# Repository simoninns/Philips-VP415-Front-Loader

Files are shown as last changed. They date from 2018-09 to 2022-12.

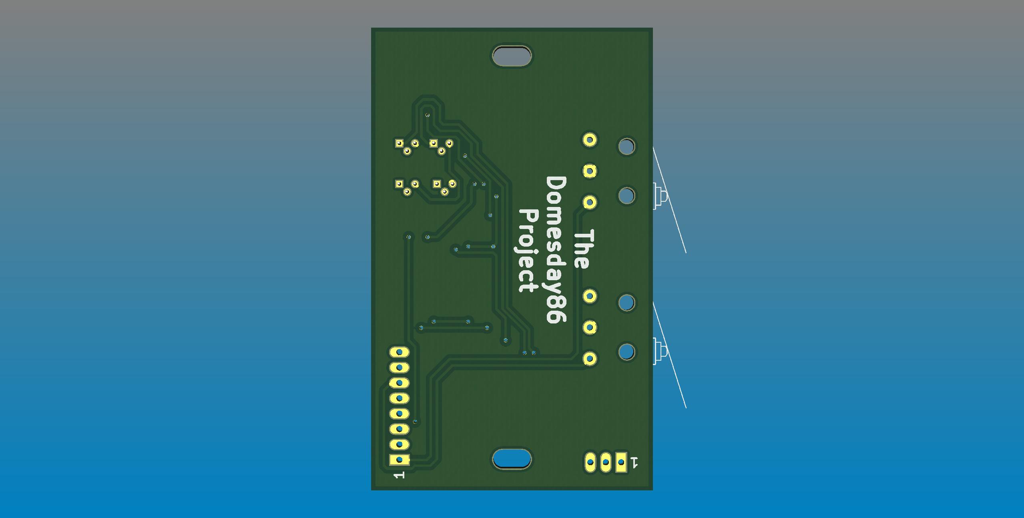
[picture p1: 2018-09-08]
Philips-VP415-Front-Loader PCB bottom.jpg

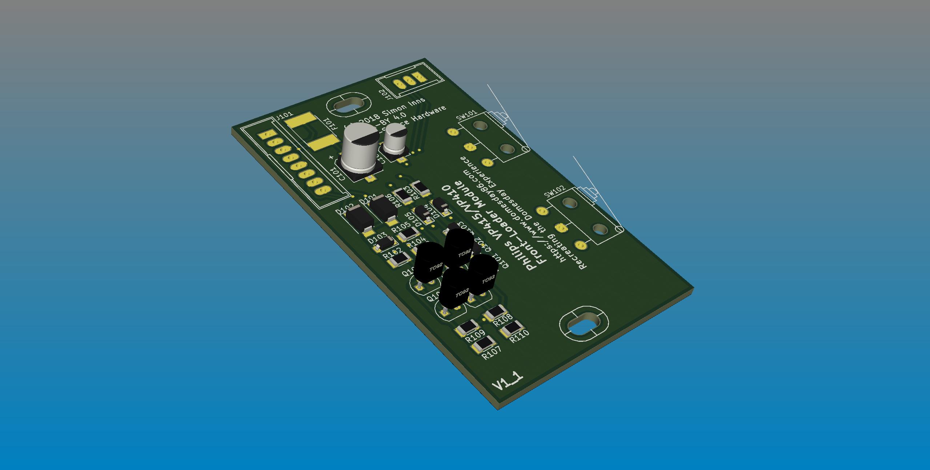
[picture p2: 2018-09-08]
Philips-VP415-Front-Loader PCB 3D render.jpg

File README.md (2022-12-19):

# Philips-VP415-Front-Loader
Replacement front-loader module (P) for the Philips VP415 Domesday LaserVision player

For more information, please see [the project wiki](https://github.com/simoninns/Philips-VP415-Front-Loader/wiki)

## Synopsis

This card is designed as a drop-in replacement for the original Philips VP415 LaserVision player's front-loader module (P).

## Motivation

The original front loader module uses custom Philips microswitches which can no longer be sourced.  The front-loader module is responsible for detecting the closure of the disc tray and the switches are impacted everytime a LaserDisc is loaded making it a common failure point in VP415s.  In addition, since the disc tray can vibrate during transport, the front-loader module is often damaged when players are moved.

The new module design is intended to use modern components and act as a drop-in replacement for the original requiring no alteration to the VP415.

## Author

The Philips VP415 replacement front-loader module was designed by Simon Inns.

## License

This project is released under a Creative Commons Attribution-ShareAlike 4.0 International (CC BY-SA 4.0) licence.

You are free to:

Share � copy and redistribute the material in any medium or format
Adapt � remix, transform, and build upon the material
for any purpose, even commercially.

This license is acceptable for Free Cultural Works.

The licensor cannot revoke these freedoms as long as you follow the license terms.

Under the following terms:

Attribution � You must give appropriate credit, provide a link to the license,
and indicate if changes were made. You may do so in any reasonable manner, but
not in any way that suggests the licensor endorses you or your use.

ShareAlike � If you remix, transform, or build upon the material, you must
distribute your contributions under the same license as the original.

No additional restrictions � You may not apply legal terms or technological
measures that legally restrict others from doing anything the license permits.

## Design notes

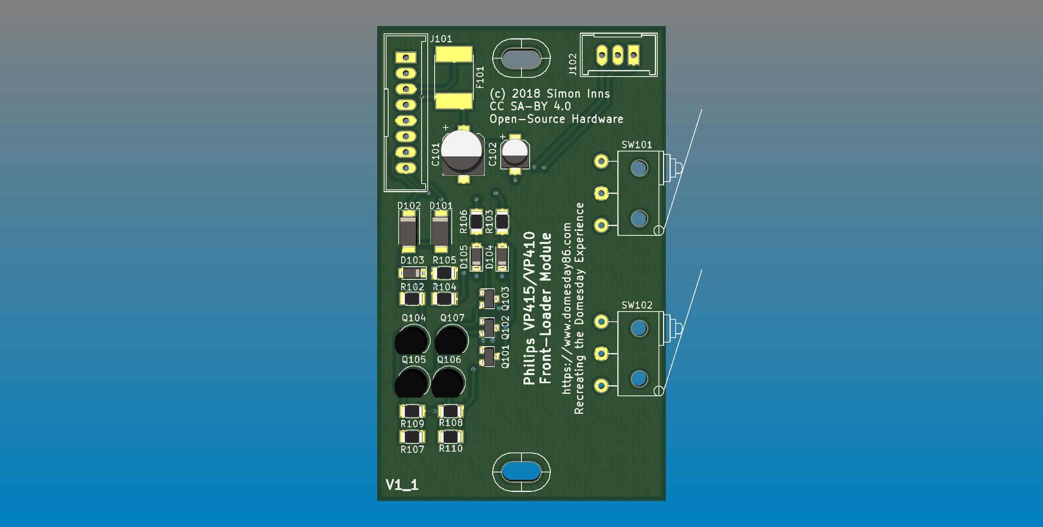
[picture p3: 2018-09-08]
Philips-VP415-Front-Loader PCB top.jpg

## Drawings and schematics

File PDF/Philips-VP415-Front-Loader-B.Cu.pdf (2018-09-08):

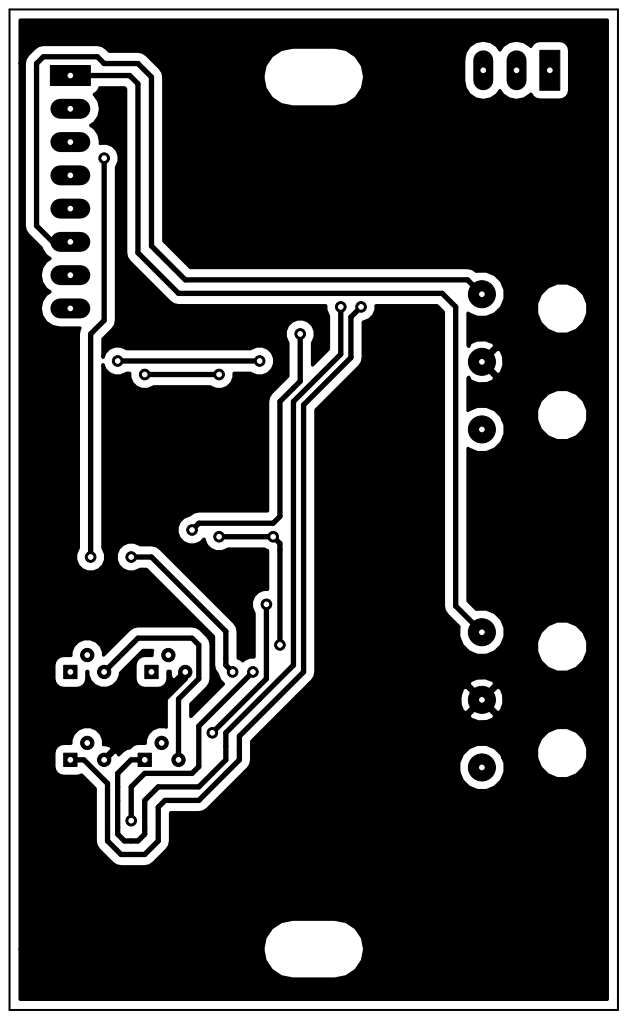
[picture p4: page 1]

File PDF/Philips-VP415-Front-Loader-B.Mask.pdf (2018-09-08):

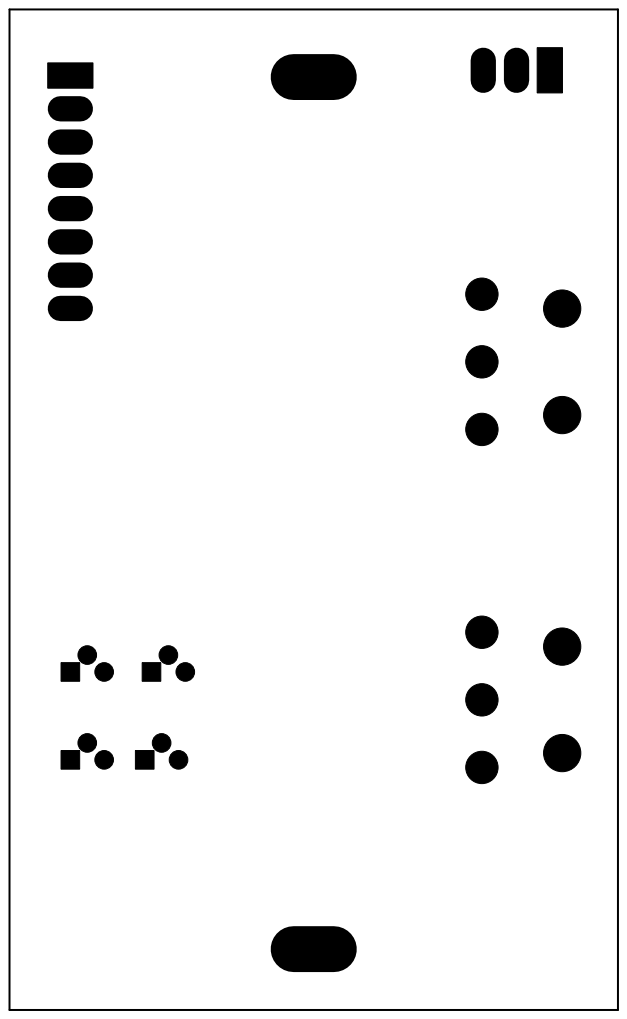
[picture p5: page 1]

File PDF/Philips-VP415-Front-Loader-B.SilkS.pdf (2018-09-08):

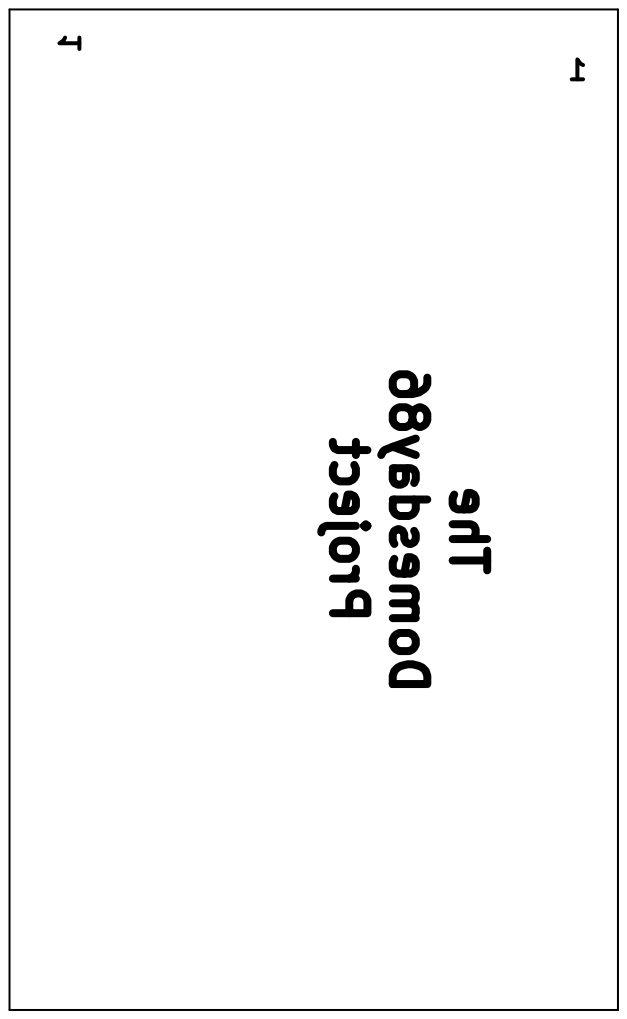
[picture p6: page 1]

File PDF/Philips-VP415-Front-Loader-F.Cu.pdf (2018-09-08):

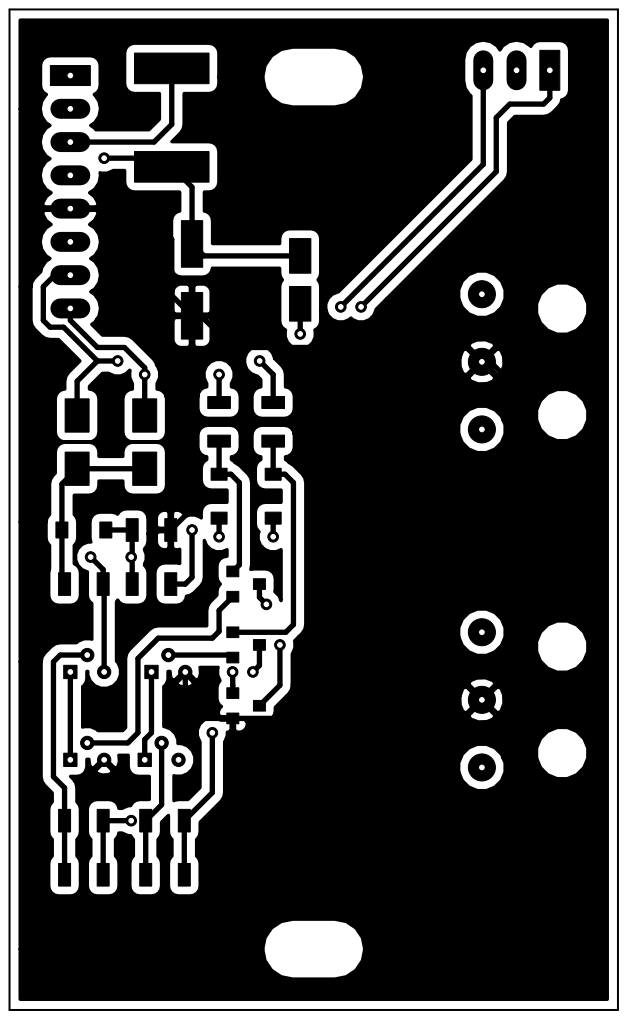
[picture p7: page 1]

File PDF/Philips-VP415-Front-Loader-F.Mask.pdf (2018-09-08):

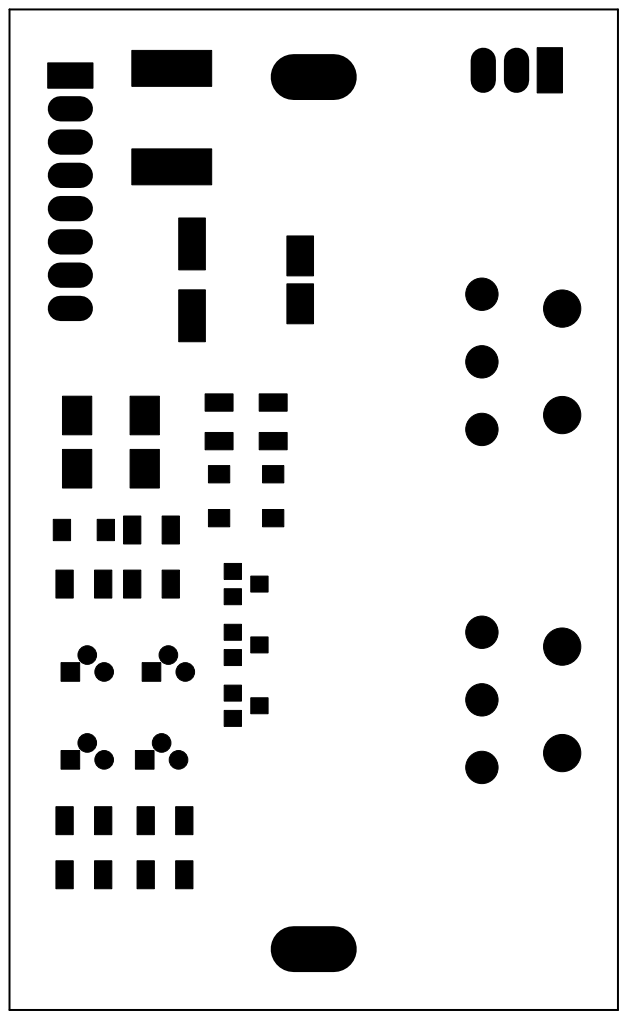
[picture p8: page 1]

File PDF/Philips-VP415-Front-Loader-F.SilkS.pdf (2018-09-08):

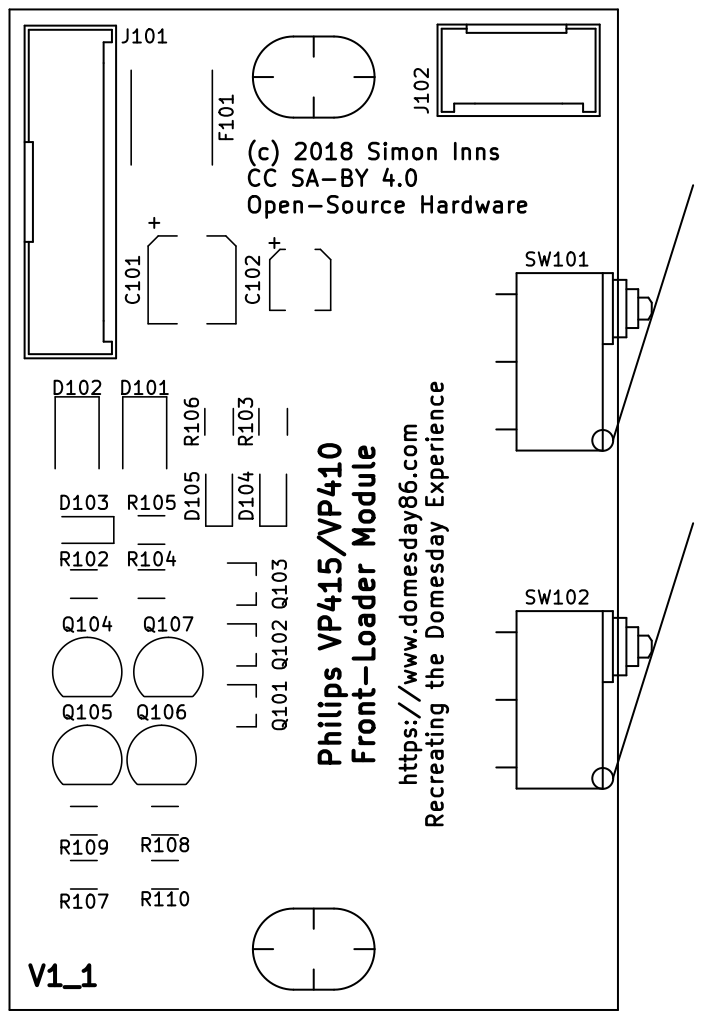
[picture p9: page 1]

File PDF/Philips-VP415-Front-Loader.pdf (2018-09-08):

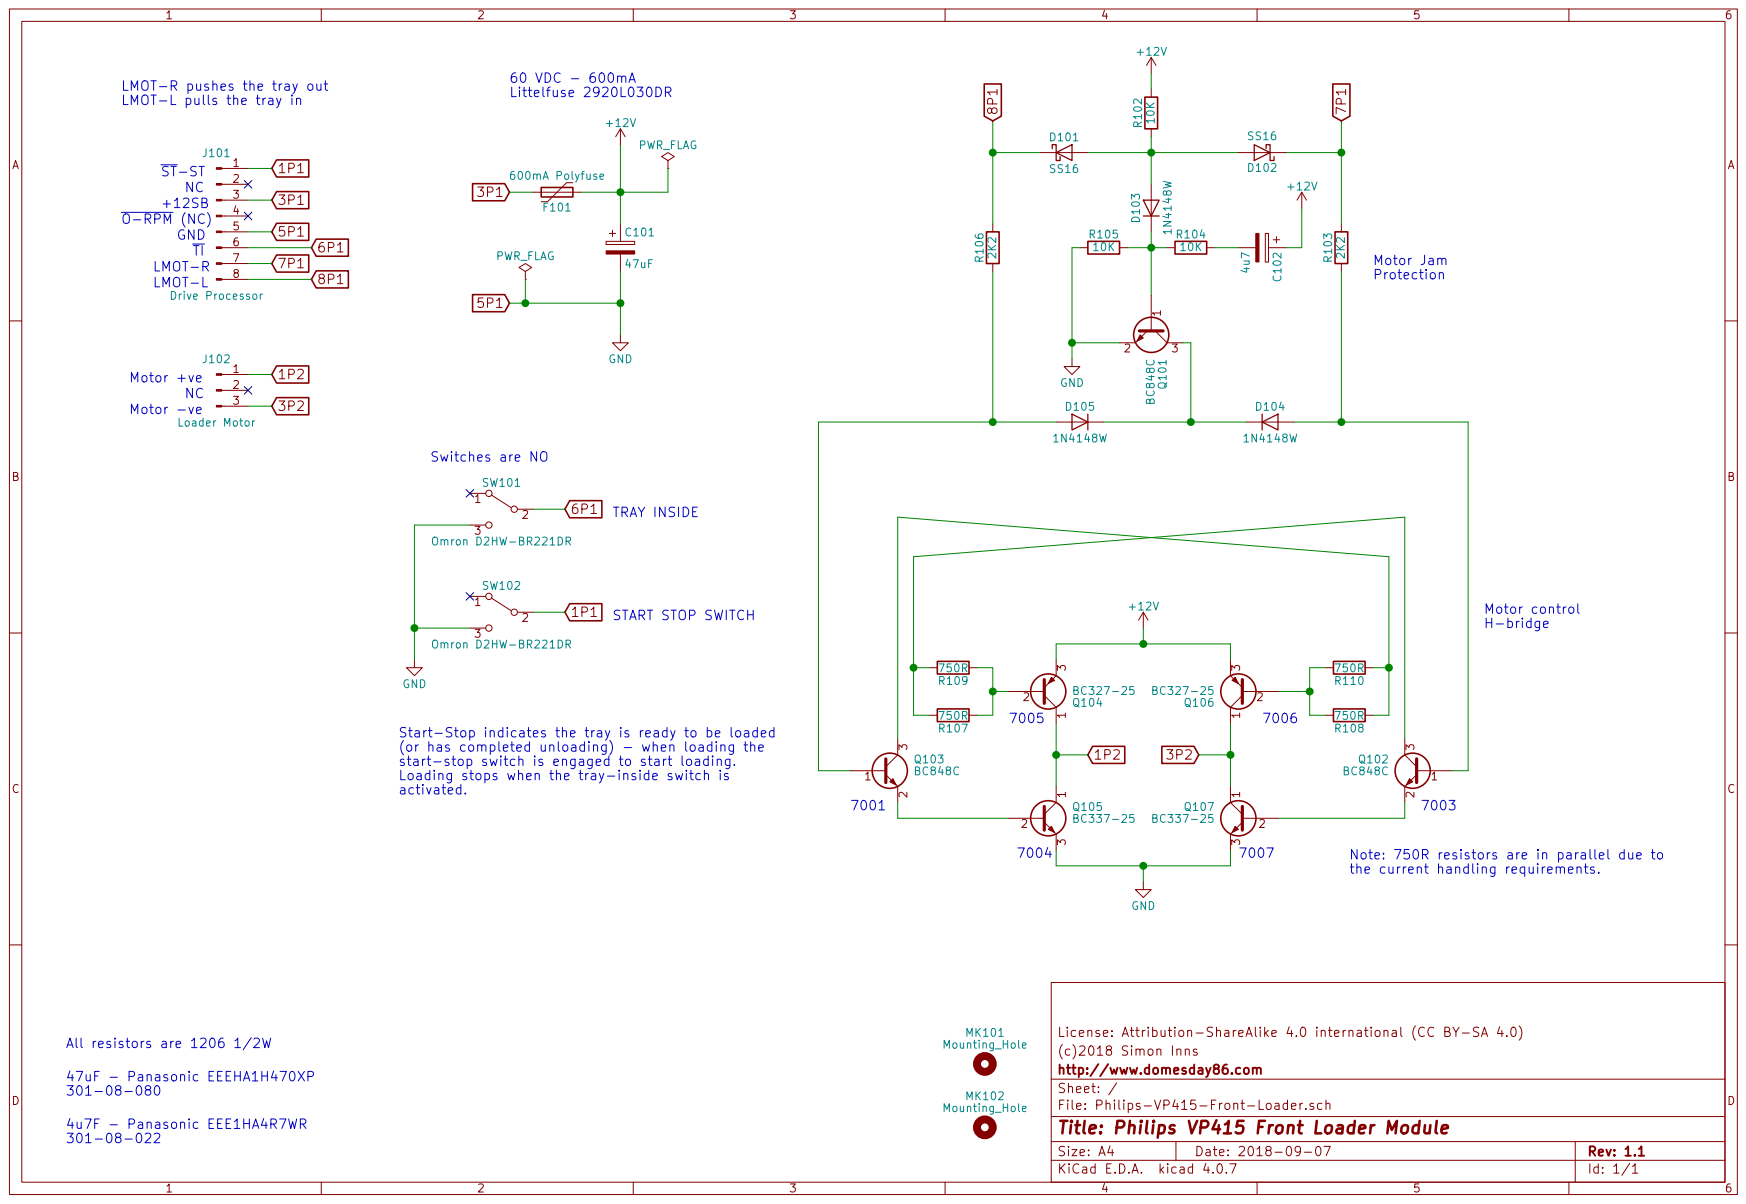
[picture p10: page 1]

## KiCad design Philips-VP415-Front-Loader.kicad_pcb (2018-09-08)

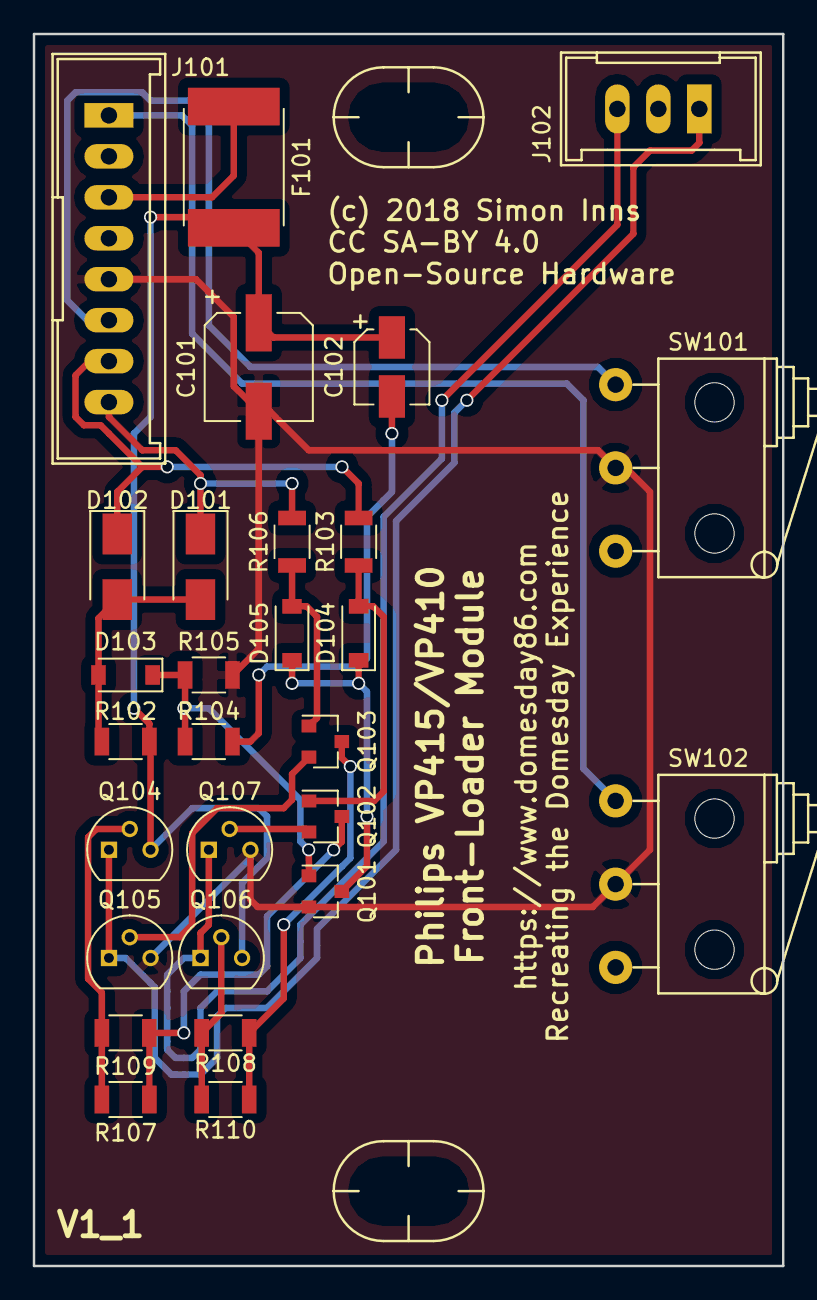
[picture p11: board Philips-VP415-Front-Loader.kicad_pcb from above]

Board: 2 copper layers, 45.7 x 75.2 mm, 30 parts (0 on the bottom side), 21 nets.

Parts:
C101: 47uF; CP_Elec_6.3x7.7
C102: 4u7; CP_Elec_4x5.3
D101, D102: SS16; D_SMA
D103, D104, D105: 1N4148W; D_SOD-123
F101: 600mA Polyfuse; Fuse_SMD2920
J101: Drive Processor; Lumberg-25-MSF-08
J102: Loader Motor; Lumberg-25-MSF-03
MK101, MK102: Mounting_Hole; Module-P-Mount
Q101, Q102, Q103: BC848C; SOT-23
Q104, Q106: BC327-25; TO-92_Molded_Narrow
Q105, Q107: BC337-25; TO-92_Molded_Narrow
R102, R104, R105: 10K; R_1206
R103, R106: 2K2; R_1206
R107, R108, R109, R110: 750R; R_1206
SW101, SW102: Omron D2HW-BR221DR; D2HW-8BR221DR

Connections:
1P1: J101.1, SW102.2
1P2: J102.1, Q104.1, Q105.1
3P1: F101.1, J101.3
3P2: J102.3, Q106.1, Q107.1
5P1: C101.2, J101.5, Q101.2, Q105.3, Q107.3, R105.1, SW101.3, SW102.3
6P1: J101.6, SW101.2
7P1: D102.1, J101.7, R103.2
8P1: D101.1, J101.8, R106.2
+12V: C101.1, C102.1, F101.2, Q104.3, Q106.3, R102.2
unnamed: C102.2, R104.2
unnamed: D101.2, D102.2, D103.2, R102.1
unnamed: D103.1, Q101.1, R104.1, R105.2
unnamed: D104.1, D105.1, Q101.3
unnamed: D104.2, Q102.1, R103.1
unnamed: D105.2, Q103.1, R106.1
unnamed: Q102.2, Q107.2
unnamed: Q102.3, R107.2, R109.2
unnamed: Q103.2, Q105.2
unnamed: Q103.3, R108.1, R110.1
unnamed: Q104.2, R107.1, R109.1
unnamed: Q106.2, R108.2, R110.2

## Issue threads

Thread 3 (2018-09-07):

B530C diodes are to big

simoninns, 2018-09-07:
B530C diodes are totally over kill.  Should be swapped for SS16s which are smaller, cheaper and better rated for the application.

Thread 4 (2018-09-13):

Q105 position

simoninns, 2018-09-13:
When the board is mounted at the far-left extent, Q105 is resting against the disc-tray.  Q105 could do with being mounted a little more to the right in the next revision of the PCB.

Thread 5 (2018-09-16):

Start-stop switch position

simoninns, 2018-09-16:
In the two players I've installed these boards in, both required the board to be shifted left a couple of millimetres when mounting - the start-stop switch should be moved 2mm up the board to 'centralize' the calibration a little better.

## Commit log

2018-07-22 Initial draft of schematic in KiCAD
    [Philips-VP415-Front-Loader.kicad_pcb, Philips-VP415-Front-Loader.sch]
2018-07-23 Added switch footprint and minor schematic updates
    [Philips-VP415-Front-Loader.sch]
2018-07-23 Added custom mounting holes
    [Philips-VP415-Front-Loader.sch]
2018-07-23 Added Lumberg connector footprints
2018-07-23 Initial layout of major components on PCB
    [Philips-VP415-Front-Loader.kicad_pcb, Philips-VP415-Front-Loader.sch]
2018-07-23 Finished design ready for testing
    [Philips-VP415-Front-Loader-B.Cu.gbr, Philips-VP415-Front-Loader-B.Mask.gbr, Philips-VP415-Front-Loader-B.SilkS.gbr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]
2018-07-24 Updates to components and added version number to silkscreen
    [Philips-VP415-Front-Loader-B.Cu.gbr, Philips-VP415-Front-Loader-B.Mask.gbr, Philips-VP415-Front-Loader-B.SilkS.gbr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]
2018-09-07 Correction to schematic for issue #2 - requires PCB redesign
    [Philips-VP415-Front-Loader.kicad_pcb, Philips-VP415-Front-Loader.sch]
2018-09-08 Modifications to circuit
    Replaced BD140/BD139s with cheaper BC337/BC327 transistors
    Replaced NFR with SMD polyfuse
    [Philips-VP415-Front-Loader.kicad_pcb, Philips-VP415-Front-Loader.sch]
2018-09-08 New V1_1 board layout
    [Philips-VP415-Front-Loader-B.Cu.gbr, Philips-VP415-Front-Loader-B.Mask.gbr, Philips-VP415-Front-Loader-B.SilkS.gbr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]

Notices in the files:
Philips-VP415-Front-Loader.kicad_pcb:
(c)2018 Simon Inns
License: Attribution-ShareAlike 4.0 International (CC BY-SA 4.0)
